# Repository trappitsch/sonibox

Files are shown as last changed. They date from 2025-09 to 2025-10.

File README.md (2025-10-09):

# sonibox

A music box. Plays music from a specific folder when an RFID tag is placed on the reader.
If you want to build this, e.g., for your kid, I highly recommend to add more than 5 songs 
to any given playlist... or add more later ;)

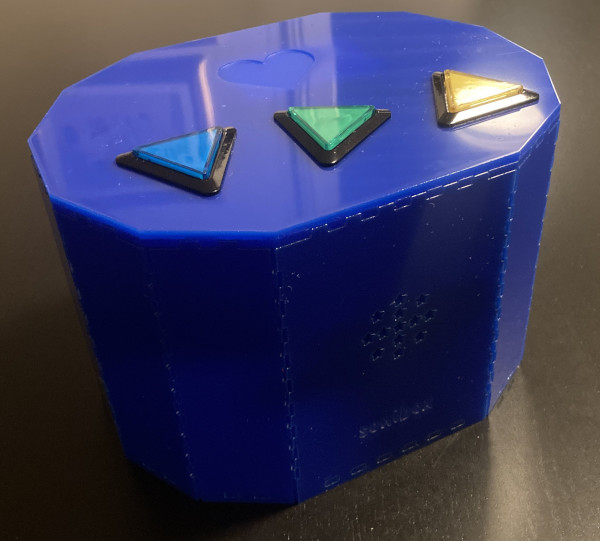
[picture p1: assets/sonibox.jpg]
my first version of the box


## Approximate BOM, but you can use similar parts, vary as needed!

- [Raspberry Pi Pico 2040](https://www.raspberrypi.com/products/raspberry-pi-pico/)
- An MFRC522 RFID reader, e.g., [this one](https://www.velleman.eu/products/view/arduino-compatible-rfid-read-and-write-module-vma405/?id=435568&lang=en)
- [DFRobot Mini MP3 player](https://wiki.dfrobot.com/DFPlayer_Mini_SKU_DFR0299) and a microSD card with music
- [Speaker](https://www.digikey.ch/de/products/detail/pui-audio-inc/ASE06008MR-LW150-R/4700909)
- [Battery pack with charging circuit](https://www.dfrobot.com/product-2578.html)
- [Three triangle buttons](https://www.adafruit.com/product/4187)
- USB C panel mount to charge battery from outside
- Panel mount push button soldered to battery On/Off switch for external control
- Standoffs, screws, heat inserts, wires.
- PCB (see `pcb` folder)
- Laser cut enclosure (see `enclosure` folder)

## PCB 

The PCB is designed in KiCad, see the `pcb` folder. 
Production files for JLCPCB are in the `pcb/jlcpcb` folder. 
Assembly needs to be done by hand using through-hole components.

For the connectors you can use any 2.54mm pitch pin headers or 
similar sized Molex connectors (as a nice alternative).

## Enclosure

An outline of the enclosure is shown in the `enclosure` folder.
This is designed for 3mm acrylic. 
Many boxes are possible, this is just one example I liked.
Check out [this site](https://boxes.hackerspace-bamberg.de/) for more ideas!

## Firmware 

The firmware is written in Rust and uses 
[embassy](https://embassy.dev/) as the async executor. 
After 5 min of inactivity, the box will stop polling the RFID reader 
to save power, however, the current version does not put the MP3 player 
or the power button LED (if present) to sleep. A future version could however 
do that! However, using a beefy battery helps a lot even with these shortcomings.

A shout out to [1-rafael-1](https://github.com/1-rafael-1/), the maintainer of 
the [dfplayer-async](https://docs.rs/dfplayer-async/latest/dfplayer_async/) crate. 
Also a big thank you to the [embassy](https://embassy.dev/) team for this amazing tool 
and for fostering a very friendly and helpful community!

## Todo

- [ ] Add a watchdog to reset the Pico if some task gets stuck
- [ ] Add functionality to really put all power drawing components to sleep after inactivity (requires hardware mods)
- [ ] Add some better LED animations when the music plays. Something random? 

## License

This project is licensed under the MIT License - see the [LICENSE](LICENSE) file for details.

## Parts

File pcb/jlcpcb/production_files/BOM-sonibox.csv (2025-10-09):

Comment | Designator | Footprint | LCSC | Quantity
500 | R6 | R_Axial_DIN0207_L6.3mm_D2.5mm_P10.16mm_Horizontal |  | 1
1k | R1 | R_Axial_DIN0207_L6.3mm_D2.5mm_P10.16mm_Horizontal |  | 1
22112042 | J5 | CONN_A-6373-04A_MOL |  | 1
22112022 | J7 | CONN_A-6373-02A_MOL |  | 1
RFID Reader | J1 | SAMTEC_TS-108-X-A-1 |  | 1
22112022 | J2 | CONN_A-6373-02A_MOL |  | 1
1k | R3 | R_Axial_DIN0207_L6.3mm_D2.5mm_P10.16mm_Horizontal |  | 1
500 | R2 | R_Axial_DIN0207_L6.3mm_D2.5mm_P10.16mm_Horizontal |  | 1
DFR0299 | U1 | MODULE_DFR0299 |  | 1
22112042 | J3 | CONN_A-6373-04A_MOL |  | 1
22112022 | J6 | CONN_A-6373-02A_MOL |  | 1
22112042 | J4 | CONN_A-6373-04A_MOL |  | 1
1k | R5 | R_Axial_DIN0207_L6.3mm_D2.5mm_P10.16mm_Horizontal |  | 1
RaspberryPi_Pico | A1 | RaspberryPi_Pico_Common_Unspecified |  | 1
1N5817 | D1 | D_DO-41_SOD81_P10.16mm_Horizontal |  | 1
500 | R4 | R_Axial_DIN0207_L6.3mm_D2.5mm_P10.16mm_Horizontal |  | 1

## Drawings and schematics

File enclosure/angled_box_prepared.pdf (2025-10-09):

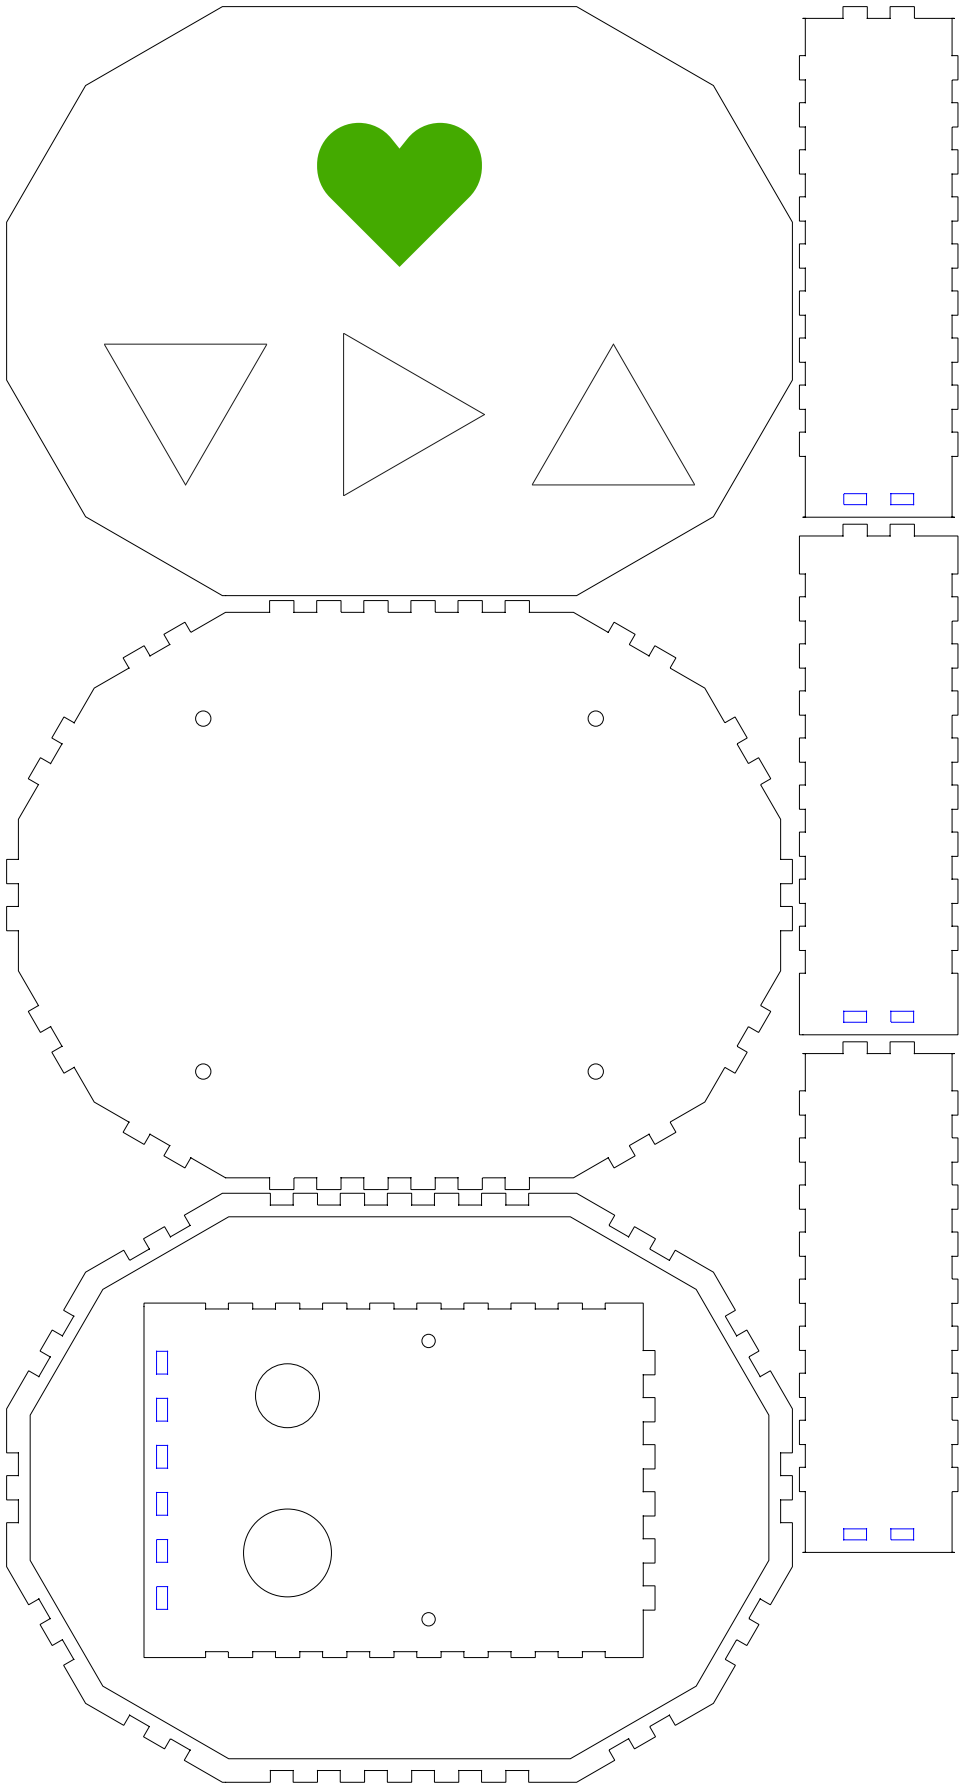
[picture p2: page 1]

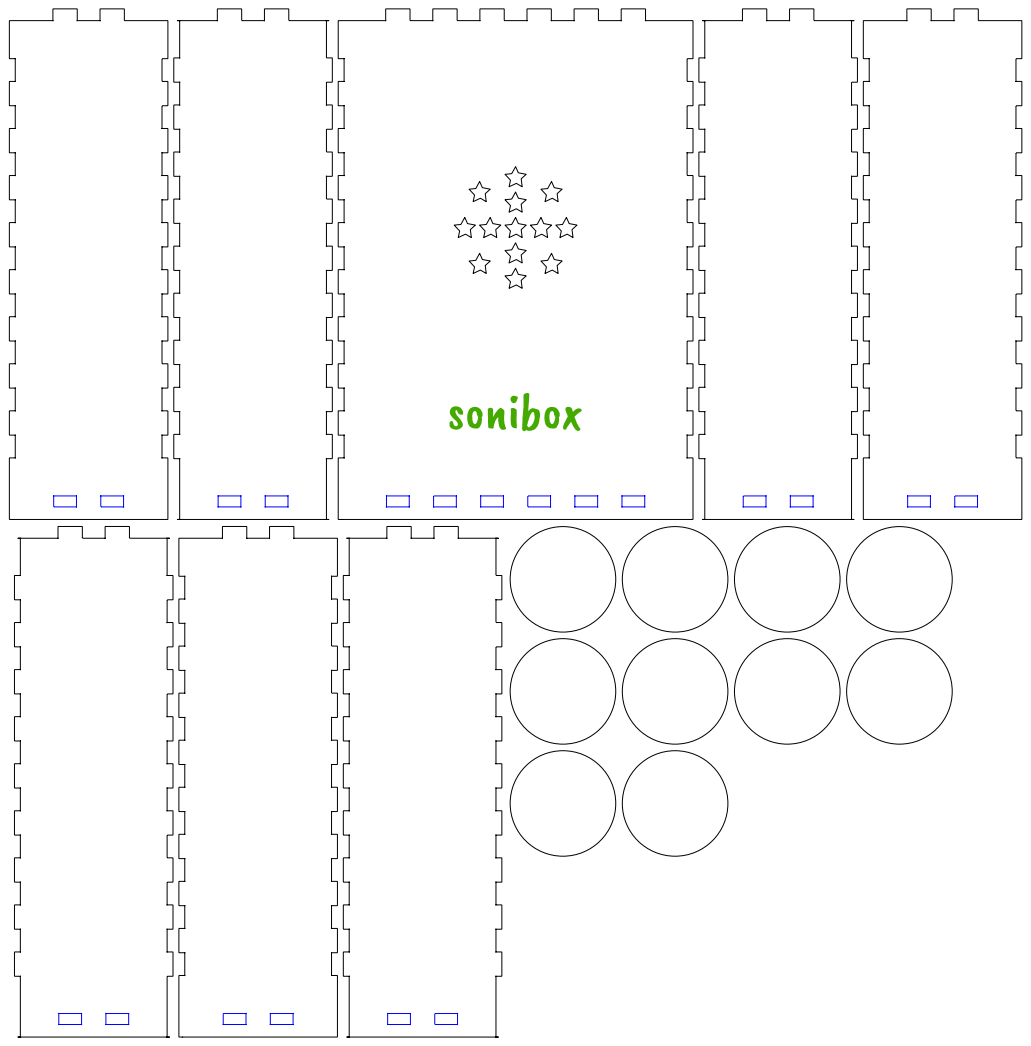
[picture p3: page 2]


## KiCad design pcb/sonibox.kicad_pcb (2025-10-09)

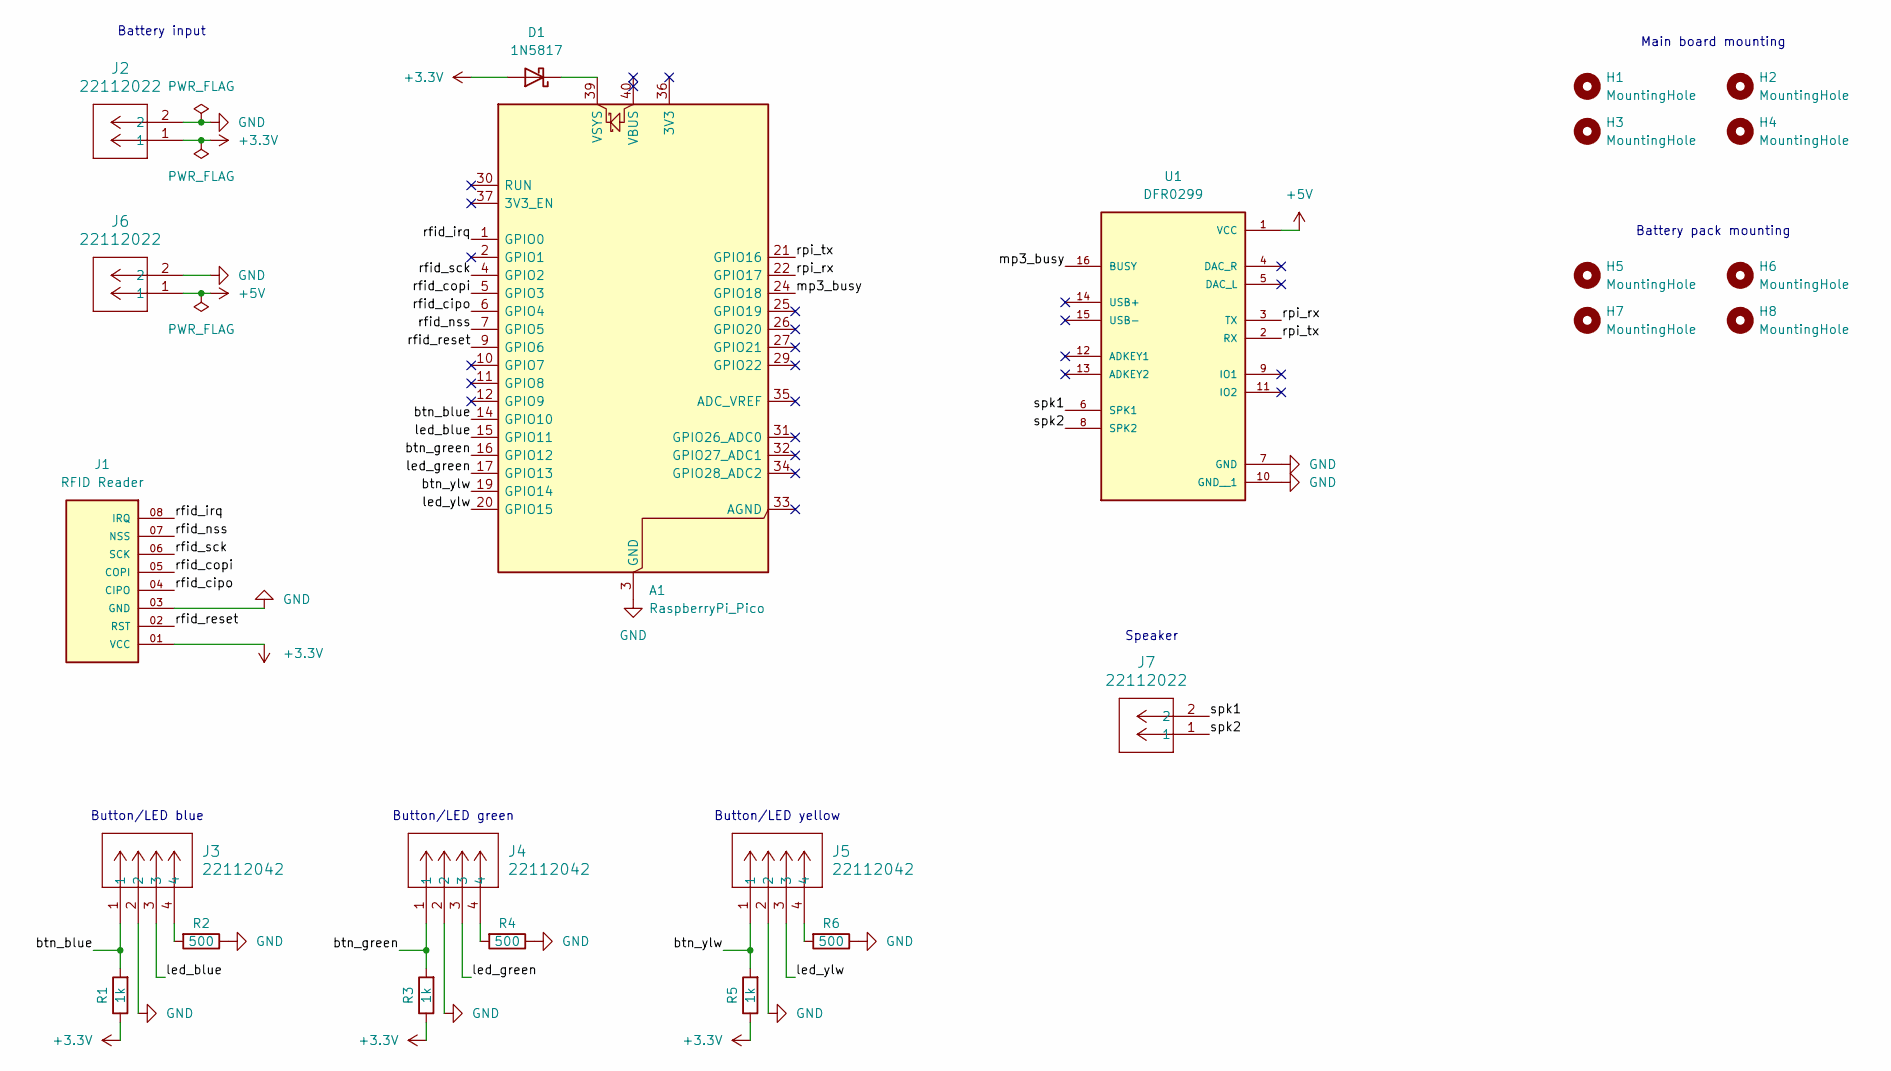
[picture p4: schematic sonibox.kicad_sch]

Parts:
A1: RaspberryPi_Pico; RaspberryPi_Pico_Common_Unspecified
D1: 1N5817; D_DO-41_SOD81_P10.16mm_Horizontal
H1, H2, H3, H4: MountingHole; MountingHole_3.2mm_M3
H5, H6, H7, H8: MountingHole; MountingHole_3mm
J1: RFID Reader; SAMTEC_TS-108-X-A-1; PARTREV B
J2, J6, J7: 22112022; CONN_A-6373-02A_MOL
J3, J4, J5: 22112042; CONN_A-6373-04A_MOL
R1, R3, R5: 1k; R_Axial_DIN0207_L6.3mm_D2.5mm_P10.16mm_Horizontal
R2, R4, R6: 500; R_Axial_DIN0207_L6.3mm_D2.5mm_P10.16mm_Horizontal
U1: DFR0299; MODULE_DFR0299

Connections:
+3.3V: D1.2 (A), J1.01 (VCC), J2.1, R1.1, R3.1, R5.1
+5V: J6.1, U1.1 (VCC)
/btn_blue: A1.14 (GPIO10), J3.1, R1.2
/btn_green: A1.16 (GPIO12), J4.1, R3.2
/btn_ylw: A1.19 (GPIO14), J5.1, R5.2
/led_blue: A1.15 (GPIO11), J3.3
/led_green: A1.17 (GPIO13), J4.3
/led_ylw: A1.20 (GPIO15), J5.3
/mp3_busy: A1.24 (GPIO18), U1.16 (BUSY)
/rfid_cipo: A1.6 (GPIO4), J1.04 (CIPO)
/rfid_copi: A1.5 (GPIO3), J1.05 (COPI)
/rfid_irq: A1.1 (GPIO0), J1.08 (IRQ)
/rfid_nss: A1.7 (GPIO5), J1.07 (NSS)
/rfid_reset: A1.9 (GPIO6), J1.02 (RST)
/rfid_sck: A1.4 (GPIO2), J1.06 (SCK)
/rpi_rx: A1.22 (GPIO17), U1.3 (TX)
/rpi_tx: A1.21 (GPIO16), U1.2 (RX)
/spk1: J7.2, U1.6 (SPK1)
/spk2: J7.1, U1.8 (SPK2)
GND: A1.3 (GND), A1.8 (GND), A1.13 (GND), A1.18 (GND), A1.23 (GND), A1.28 (GND), A1.38 (GND), J1.03 (GND), J2.2, J3.2, J4.2, J5.2, J6.2, R2.1, R4.1, R6.1, U1.7 (GND), U1.10 (GND__1)
unnamed: A1.39 (VSYS), D1.1 (K)
unnamed: J3.4, R2.2
unnamed: J4.4, R4.2
unnamed: J5.4, R6.2

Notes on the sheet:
Battery pack mounting
Speaker
Battery input
Button/LED blue
Button/LED green
Button/LED yellow
Main board mounting

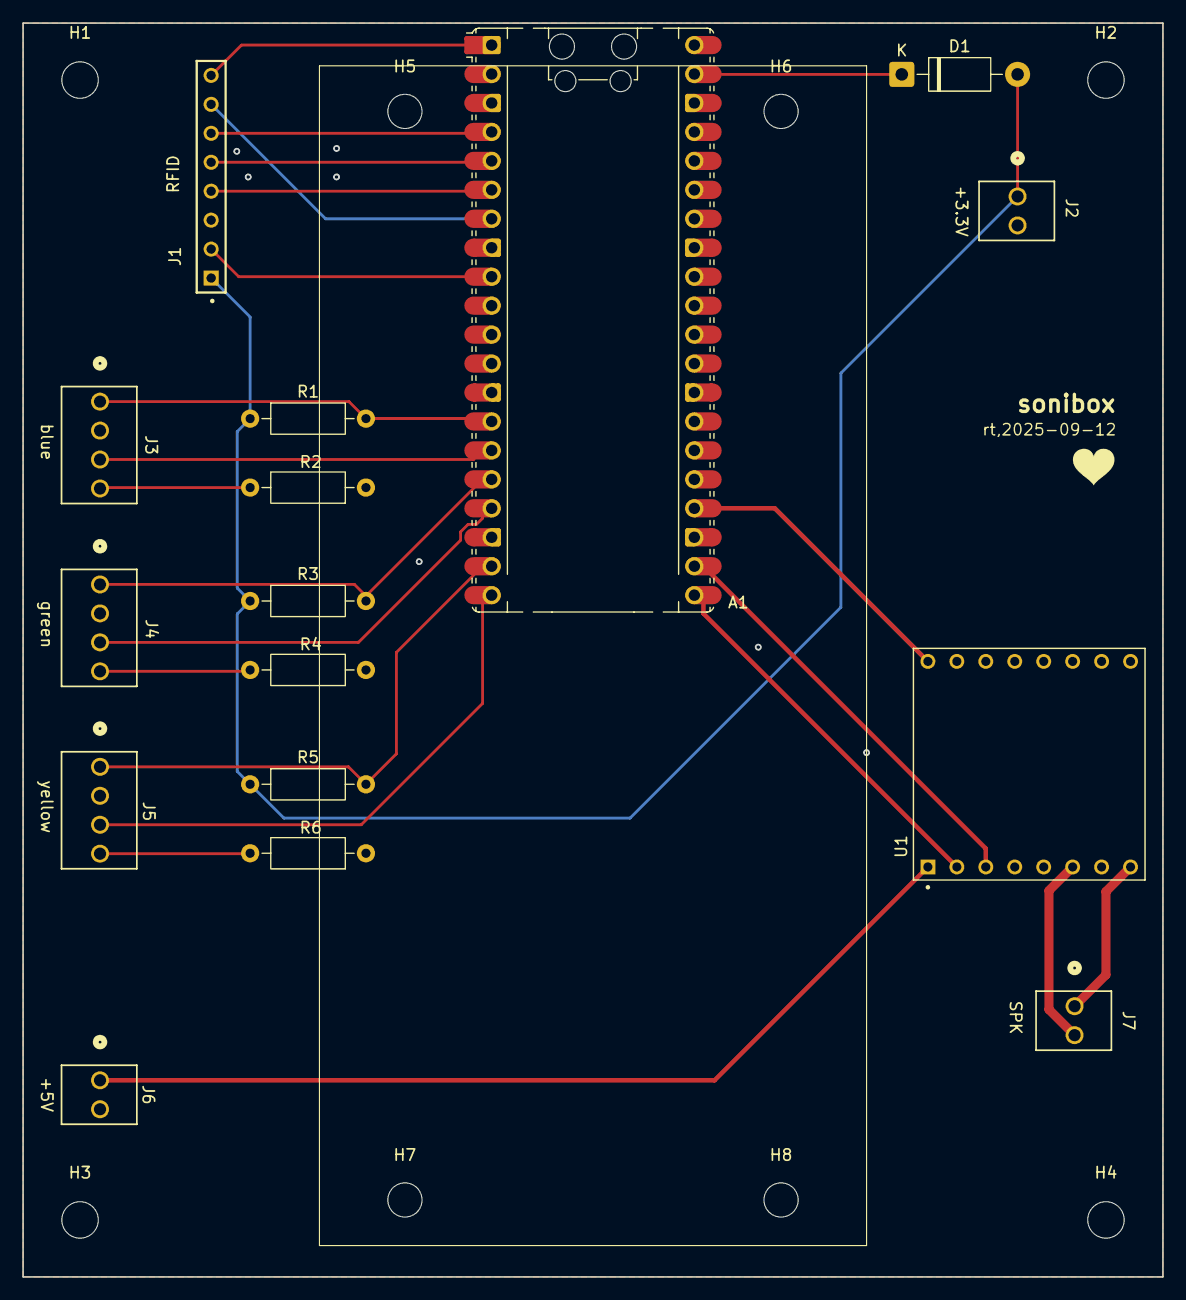
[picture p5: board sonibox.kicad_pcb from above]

Board: 2 copper layers, 100.0 x 110.0 mm, 24 parts (0 on the bottom side), 24 nets.

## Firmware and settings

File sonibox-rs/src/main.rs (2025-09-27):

#![no_std]
#![no_main]

use core::cell::RefCell;

use defmt::error;
use embassy_executor::Spawner;
use embassy_rp::{
    bind_interrupts,
    config::Config,
    gpio::{Input, Level, Output, Pull},
    peripherals::{self, UART0},
    spi::{self, Spi},
    uart::{
        BufferedInterruptHandler, BufferedUart, Config as UartConfig, DataBits, Parity, StopBits,
    },
};
use embassy_sync::blocking_mutex::{Mutex, raw::NoopRawMutex};

use defmt_rtt as _;
use leds::{LED_CMD_CHANNEL, Leds, led_task};
use panic_probe as _;
use static_cell::StaticCell;

use buttons::button_task;
use player::{PLAYER_CMD_CHANNEL, player_task};
use rfid::rfid_task;

mod buttons;
mod leds;
mod player;
mod rfid;
mod sleep;
mod tags;

bind_interrupts!(pub struct Irqs {
    UART0_IRQ => BufferedInterruptHandler<UART0>;
});

type SpiBusType = Mutex<NoopRawMutex, RefCell<spi::Spi<'static, peripherals::SPI0, spi::Blocking>>>;

static TX_BUF: StaticCell<[u8; 128]> = StaticCell::new();
static RX_BUF: StaticCell<[u8; 128]> = StaticCell::new();

#[embassy_executor::main]
async fn main(spawner: Spawner) {
    let p = embassy_rp::init(Config::default());

    // set up the LEDs
    let leds = Leds::new(
        Output::new(p.PIN_11, Level::Low),
        Output::new(p.PIN_13, Level::Low),
        Output::new(p.PIN_15, Level::Low),
    );

    // set up buttons
    let btn_previous = Input::new(p.PIN_10, Pull::Up);
    let btn_play = Input::new(p.PIN_12, Pull::Up);
    let btn_next = Input::new(p.PIN_14, Pull::Up);

    // set up UART for the DFPlayer
    let mut uart_config = UartConfig::default();
    uart_config.baudrate = 9600;
    uart_config.data_bits = DataBits::DataBits8;
    uart_config.stop_bits = StopBits::STOP1;
    uart_config.parity = Parity::ParityNone;

    let tx_buf = &mut TX_BUF.init([0; 128])[..];
    let rx_buf = &mut RX_BUF.init([0; 128])[..];
    let uart = BufferedUart::new(
        p.UART0,
        Irqs,
        p.PIN_16,
        p.PIN_17,
        tx_buf,
        rx_buf,
        uart_config,
    );

    // set up spi for the rfid reader
    let cipo = p.PIN_4;
    let copi = p.PIN_3;
    let clk = p.PIN_2;
    let touch_cs = p.PIN_5;
    let touch_cs_out = Output::new(touch_cs, Level::High);

    // create SPI for RFID reader
    let spi_blocking = Spi::new_blocking(p.SPI0, clk, copi, cipo, spi::Config::default());
    let spi_bus: SpiBusType = Mutex::new(RefCell::new(spi_blocking));

    spawner.must_spawn(led_task(leds));
    spawner.must_spawn(player_task(uart));
    spawner.must_spawn(button_task(
        btn_previous,
        btn_play,
        btn_next,
    ));
    spawner.must_spawn(rfid_task(
        spi_bus,
        touch_cs_out,
        PLAYER_CMD_CHANNEL.sender(),
    ));

    let mut sleep_timer = sleep::SleepTimer::new();

    loop {
        sleep_timer.wait().await; // this should never return unless something went bad...
        error!("The sleep timer wait loop terminated. This should not happen.");
        LED_CMD_CHANNEL.send(leds::LedCommand::Error).await;
    }
}

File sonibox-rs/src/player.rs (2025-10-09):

//! Player module for handling playback-related functionality.

use defmt::{Debug2Format, error, info};
use dfplayer_async::{DfPlayer, TimeSource};
use embassy_rp::{peripherals as p, uart::BufferedUart};
use embassy_sync::{
    blocking_mutex::raw::ThreadModeRawMutex,
    channel::{Channel, Sender},
};
use embassy_time::{Delay, Duration, Instant, Timer};

use crate::leds::{LED_CMD_CHANNEL, LedCommand};

pub type PlayerCmdChannel = Channel<ThreadModeRawMutex, PlayerCommand, 16>;
pub type PlayerCmdSender = Sender<'static, ThreadModeRawMutex, PlayerCommand, 16>;
pub static PLAYER_CMD_CHANNEL: PlayerCmdChannel = Channel::new();

// A channel that will send the player status. To request it, send a playercommand
pub static PLAYER_STAT_CHANNEL: Channel<ThreadModeRawMutex, PlayerStatus, 16> = Channel::new();

#[derive(Debug)]
pub enum PlayerCommand {
    PlayFolder(u8), // Play a specific folder
    PlayPause,      // Just play after a pause
    Stop,           // Stop playback
    Next,           // Play the next track
    Previous,       // Play the previous track
    VolumeUp,       // Increase volume
    VolumeDown,     // Decrease volume
    GetStatus,      // Get the player to emit a PLAYER_STAT_CHANNEL signal
}

#[derive(Copy, Clone, Debug, PartialEq)]
pub enum PlayerStatus {
    Playing, // can be paused (button) or stopped (remove figure)
    Paused,  // playback is paused but figure is still present
    Stopped, // playback is stopped because there is no figure
}

/// Volume structure. Minimum is 0, maximum is 30.
struct Volume {
    current: u8,
}

impl Volume {
    fn new() -> Self {
        Self { current: 15 }
    }

    fn increase_volume(&mut self) {
        if self.current < 30 {
            self.current += 1;
        }
    }

    fn decrease_volume(&mut self) {
        if self.current > 0 {
            self.current -= 1;
        }
    }
}

impl PlayerStatus {
    pub fn is_playing(&self) -> bool {
        self == &PlayerStatus::Playing
    }

    pub fn is_stopped(&self) -> bool {
        self == &PlayerStatus::Stopped
    }

    fn pause(&mut self) {
        *self = PlayerStatus::Paused;
    }

    fn play(&mut self) {
        *self = PlayerStatus::Playing;
    }

    fn stop(&mut self) {
        *self = PlayerStatus::Stopped;
    }
}

/// The required time source for the player module, implemented as in the example.
struct MyTimeSource;

impl TimeSource for MyTimeSource {
    type Instant = Instant;

    fn now(&self) -> Self::Instant {
        Instant::now()
    }

    fn is_elapsed(&self, since: Self::Instant, timeout_ms: u64) -> bool {
        Instant::now().duration_since(since) >= Duration::from_millis(timeout_ms)
    }
}

#[embassy_executor::task]
pub async fn player_task(mut uart: BufferedUart<'static, p::UART0>) {
    // configuration for DFPlayer
    let feedback_enable = true;
    let timeout_ms = 1000;
    let delay = Delay;
    let reset_during_override = None;

    let mut volume = Volume::new();

    let mut player_status = PlayerStatus::Stopped;

    let mut last_played: Option<u8> = None; // last folder played

    info!("Initializing DFPlayer Mini...");
    let mut dfplayer = match DfPlayer::new(
        &mut uart,
        feedback_enable,
        timeout_ms,
        MyTimeSource,
        delay,
        reset_during_override,
    )
    .await
    {
        Ok(dfplayer) => dfplayer,
        Err(e) => {
            error!(
                "Failed to initialize DFPlayer Mini: {:?}.",
                Debug2Format(&e)
            );
            LED_CMD_CHANNEL.send(LedCommand::Error).await;
            return;
        }
    };
    info!("DFPlayer Mini initialized successfully.");

    Timer::after(Duration::from_millis(100)).await; // give some time to the player to settle

    // Set up volume to intialize the player with
    match dfplayer.set_volume(volume.current).await {
        Ok(_) => info!("Standard volume set: {}", volume.current),
        Err(e) => {
            error!("Failed to set volume: {:?}", Debug2Format(&e));
        }
    }
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

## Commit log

2025-05-26 map over to esp32
2025-06-11 buttons done
2025-10-09 fix firmware with some features and leds, add kicad, add enclosure
    [BOM-sonibox.csv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]
